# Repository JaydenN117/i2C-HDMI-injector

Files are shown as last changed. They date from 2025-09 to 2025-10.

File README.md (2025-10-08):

# i2C-HDMI-injector, Code and casing. Never ordered PCB concept too.


Injects i2c signal to Dasung Paperlike Pro monitor through HDMI on modern macs, work in progress, have not ordered. 
Reversed engineered signal by simply reading with Oscilloscope.
Did not order kicad and would redo differently to make assembly easier but it was more of a learning excersize.

[Dual HDMI Breakout](https://www.amazon.com/Teansic-Connector-Female-Connectors-Transfer/dp/B0CKN298QF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)
I ended up desoldering the pins to minimize footprint so perhaps a version [Without Presoldered headers](https://www.amazon.com/Cermant-Connector-Board%EF%BC%8C2-54-Connectors-Electronics/dp/B0DGT2GBF2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) would have been a better purchase

Refresh
Refresh

Clear
Clear
<br>
Screenshot 2025-09-27 at 11 06 51 AM


Hardware: 5V level Pro Micro Soldered to HDMI breakout... Any 5V level AVR bar would work.

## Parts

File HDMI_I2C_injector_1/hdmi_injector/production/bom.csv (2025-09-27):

Designator | Footprint | Quantity | Value | LCSC Part #
C1, C2 | 0603 | 2 | 100nF
D-SCL-1, D2, D6, D7, D8 | D_SOD-882 | 5 | SP3021-01ETG
D1, D3, D9 | D_SOD-882 | 3 | PESD5V0L1UL
J1 | HDMI-SMD_HDMI-GD-132PWB | 1 | HDMI_A_MAC
J2 | HDMI-SMD_HDMI-GD-132PWB | 1 | HDMI_A_DISPLAY_SIDE
J3 | CONN_BM03B-SRSS-TBLFSN_JST | 1 | BM03B-SRSS-TBLFSN
J4 | CONN4_BM04B-SRSS_JST | 1 | BM04B-SRSS-TB
R1, R2 | 0603 | 2 | 10kΩ
R4 | 0603 | 1 | 0Ω
U1 | SOIC-8_3.9x4.9mm_P1.27mm | 1 | ATtiny402-SS
U3 | SOT-363_SC-70-6 | 1 | LM66100DCK

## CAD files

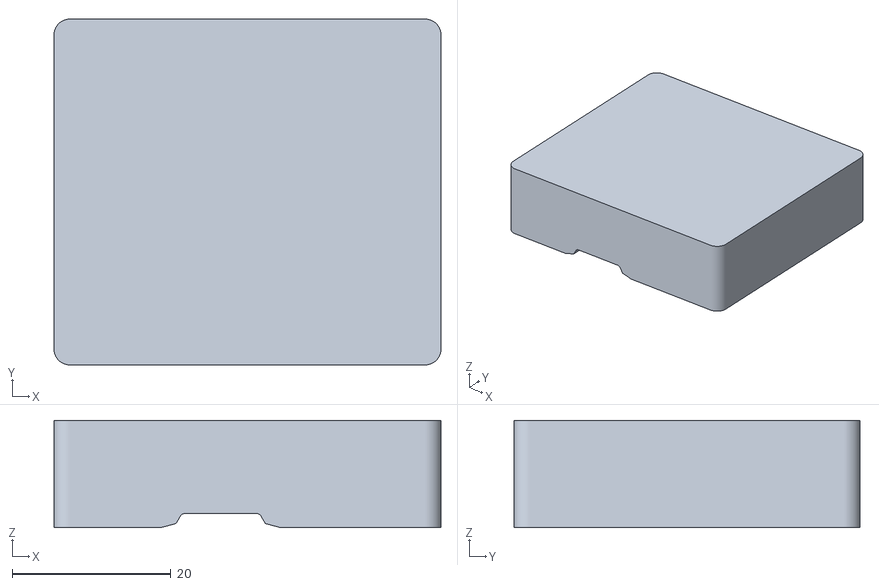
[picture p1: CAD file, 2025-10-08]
Top_casing.stl
48.7 x 43.5 x 13.5

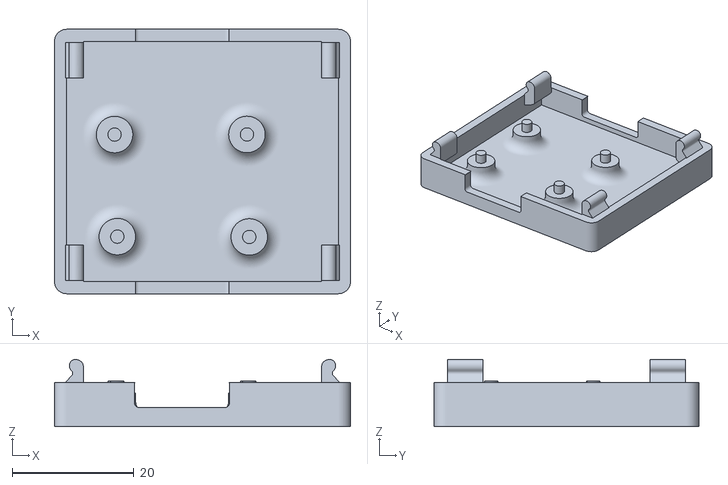
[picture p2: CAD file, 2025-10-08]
bottom_casing.stl
48.7 x 43.5 x 11.1

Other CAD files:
Hdmi board with casing v11.f3z

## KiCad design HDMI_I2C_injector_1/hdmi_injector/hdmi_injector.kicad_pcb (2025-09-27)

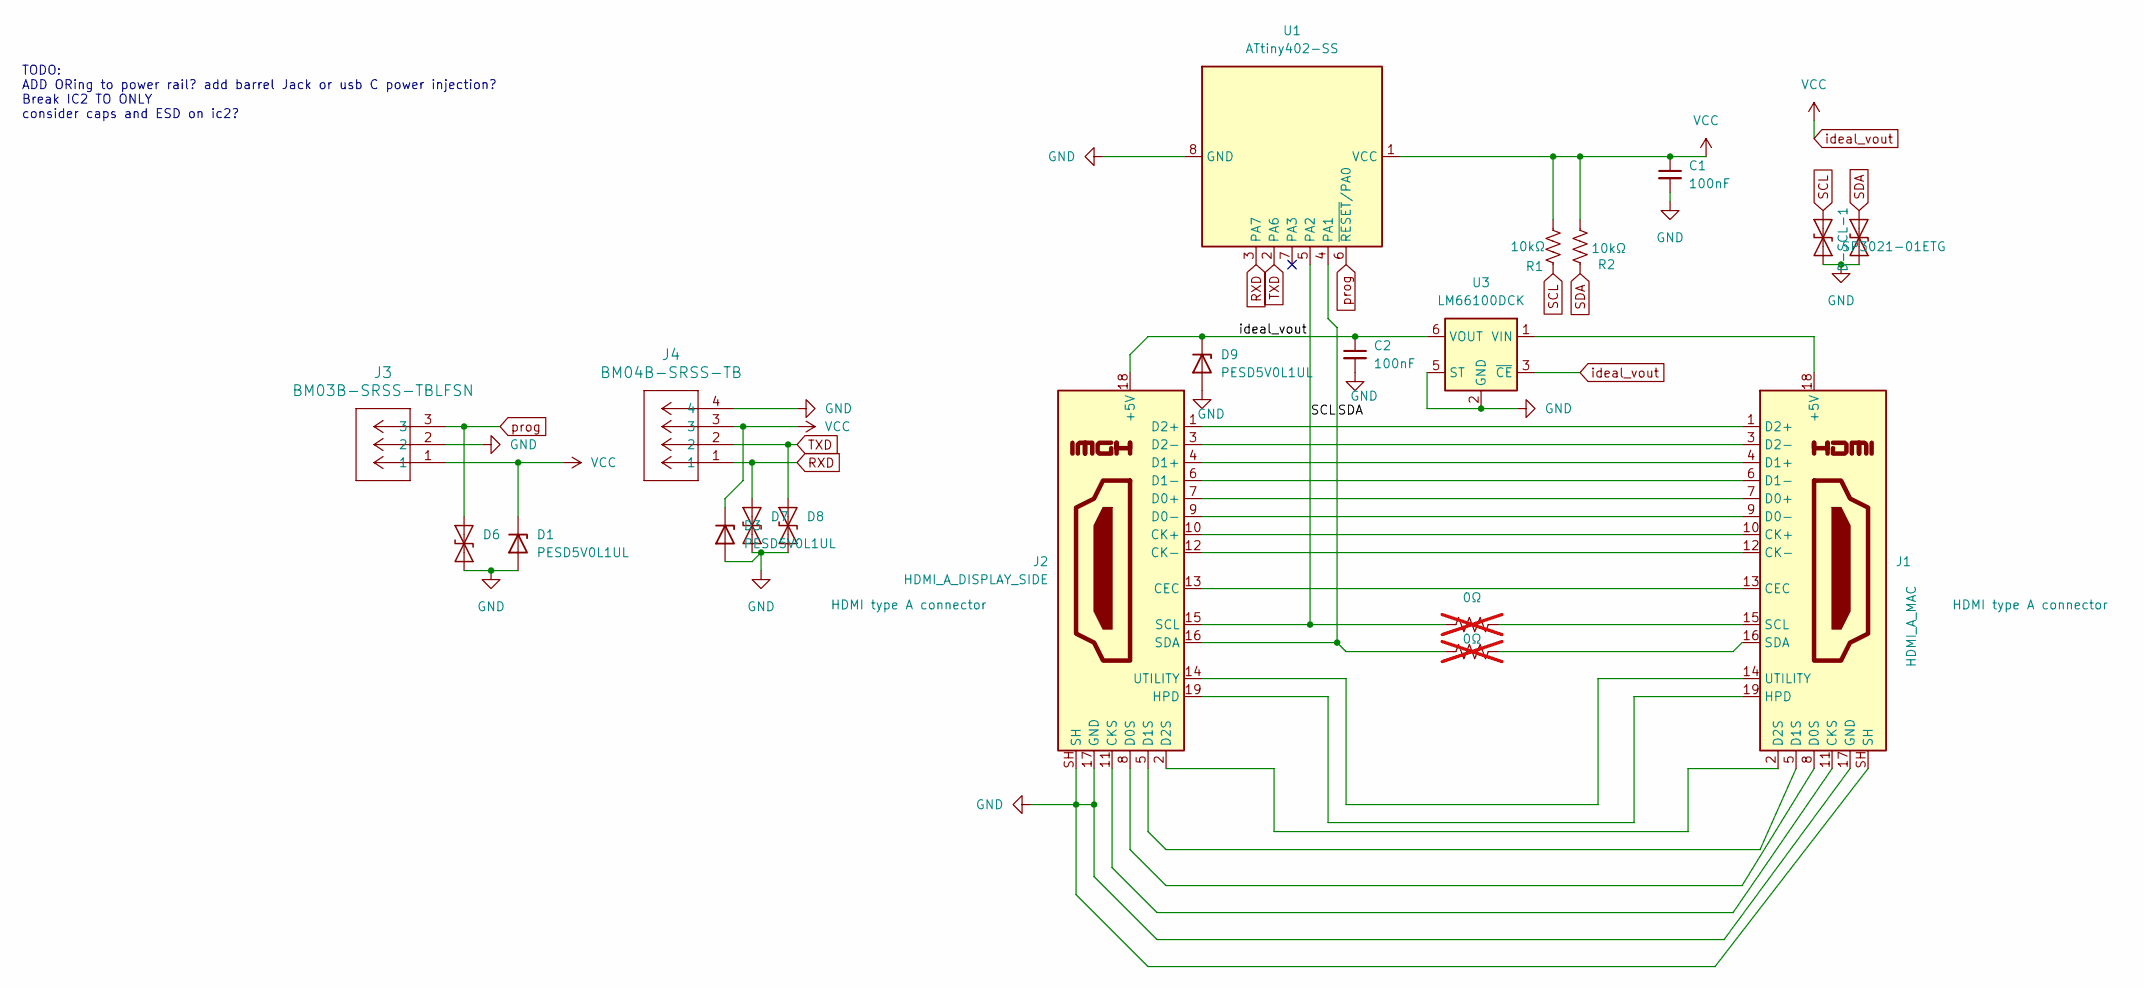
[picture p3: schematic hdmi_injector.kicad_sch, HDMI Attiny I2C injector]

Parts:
C1, C2: 100nF; C_0603_1608Metric_Pad1.08x0.95mm_HandSolder
D1, D3, D9: PESD5V0L1UL; D_SOD-882
D2, D6, D7, D8: SP3021-01ETG; D_SOD-882
D-SCL-1: SP3021-01ETG; D_SOD-882
J1: HDMI_A_MAC; HDMI-SMD_HDMI-GD-132PWB
J2: HDMI_A_DISPLAY_SIDE; HDMI-SMD_HDMI-GD-132PWB
J3: BM03B-SRSS-TBLFSN; CONN_BM03B-SRSS-TBLFSN_JST
J4: BM04B-SRSS-TB; CONN4_BM04B-SRSS_JST
R1, R2: 10kΩ; R_0603_1608Metric_Pad0.98x0.95mm_HandSolder
R3, R4: 0Ω; R_0603_1608Metric_Pad0.98x0.95mm_HandSolder; not fitted
U1: ATtiny402-SS; SOIC-8_3.9x4.9mm_P1.27mm
U3: LM66100DCK; SOT-363_SC-70-6

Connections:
GND: C1.2, C2.2, D1.2 (A), D2.1 (A1), D3.2 (A), D6.1 (A1), D7.1 (A1), D8.1 (A1), D9.2 (A), D-SCL-1.1 (A1), J1.17 (GND), J1.SH, J2.17 (GND), J2.SH, J3.2, J4.4, U1.8 (GND), U3.2 (GND), U3.5 (ST)
unnamed: J1.18 (+5V), U3.1 (VIN)
unnamed: J1.13 (CEC), J2.13 (CEC)
unnamed: J1.10 (CK+), J2.10 (CK+)
unnamed: J1.12 (CK-), J2.12 (CK-)
unnamed: J1.11 (CKS), J2.11 (CKS)
unnamed: J1.7 (D0+), J2.7 (D0+)
unnamed: J1.9 (D0-), J2.9 (D0-)
unnamed: J1.8 (D0S), J2.8 (D0S)
unnamed: J1.4 (D1+), J2.4 (D1+)
unnamed: J1.6 (D1-), J2.6 (D1-)
unnamed: J1.5 (D1S), J2.5 (D1S)
unnamed: J1.1 (D2+), J2.1 (D2+)
unnamed: J1.3 (D2-), J2.3 (D2-)
unnamed: J1.2 (D2S), J2.2 (D2S)
unnamed: J1.19 (HPD), J2.19 (HPD)
unnamed: J1.15 (SCL), R3.2
unnamed: J1.16 (SDA), R4.2
unnamed: J1.14 (UTILITY), J2.14 (UTILITY)
RXD: D7.2 (A2), J4.1, U1.3 (PA7)
SCL: D-SCL-1.2 (A2), J2.15 (SCL), R1.1, R3.1, U1.5 (PA2)
SDA: D2.2 (A2), J2.16 (SDA), R2.1, R4.1, U1.4 (PA1)
TXD: D8.2 (A2), J4.2, U1.2 (PA6)
ideal_vout: C1.1, C2.1, D1.1 (K), D3.1 (K), D9.1 (K), J2.18 (+5V), J3.1, J4.3, R1.2, R2.2, U1.1 (VCC), U3.3 (~CE), U3.6 (VOUT)
prog: D6.2 (A2), J3.3, U1.6 (~RESET/PA0)

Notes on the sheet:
TODO: ADD ORing to power rail? add barrel Jack or usb C power injection? Break IC2 TO ONLY consider caps and ESD on ic2?

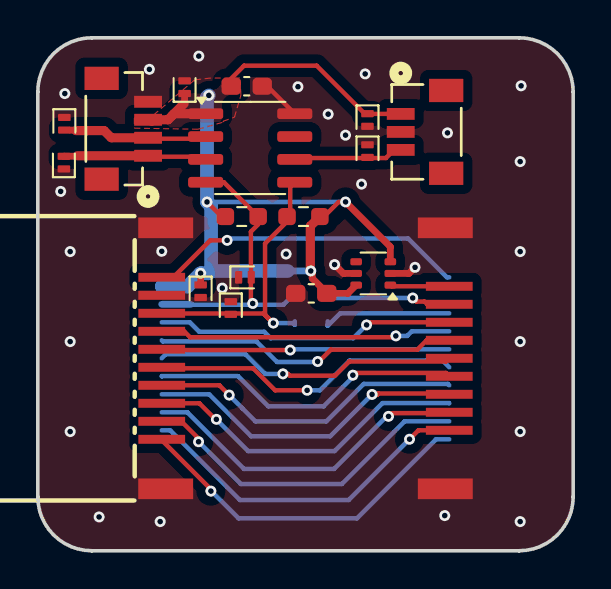
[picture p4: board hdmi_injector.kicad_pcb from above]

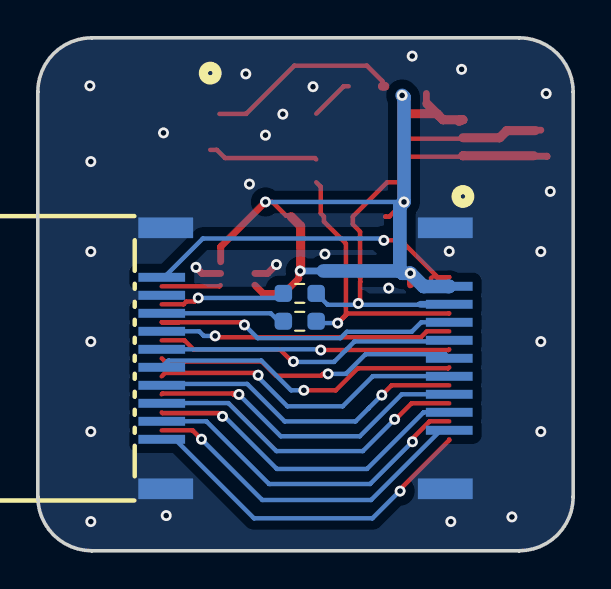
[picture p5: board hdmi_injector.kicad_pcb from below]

Board: 4 copper layers, 29.7 x 28.5 mm, 20 parts (3 on the bottom side), 25 nets.

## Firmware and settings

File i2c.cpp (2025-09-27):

#include <Arduino.h>
#include <Wire.h>

// Dasung display I2C address
const uint8_t DASUNG_I2C_ADDR = 0x37;

// Command sequences
const uint8_t CMD_SEQUENCE_1[] = {0x51, 0x84, 0x03, 0x08, 0x01, 0x01, 0xB0};
const uint8_t CMD_CLEAR[] = {0x51, 0x84, 0x03, 0x08, 0x06, 0x02, 0xB4};

void sendCommand(const uint8_t* cmd, uint8_t length) {
  Wire.beginTransmission(DASUNG_I2C_ADDR);
  for (uint8_t i = 0; i < length; i++) {
    Wire.write(cmd[i]);
  }
  Wire.endTransmission();
}

void setup() {
  // Initialize serial for debugging
  Serial.begin(115200);

  
  Serial.println("Dasung Display Hack Starting...");
  
  // Initialize I2C
  Wire.begin();
  
  // Small delay to ensure I2C is ready
  delay(100);
  
  // Send clear command on startup
  Serial.println("Sending clear command...");
  sendCommand(CMD_CLEAR, sizeof(CMD_CLEAR));
  
  delay(100);
  
  // Send the first command sequence
  Serial.println("Sending command sequence 1...");
  sendCommand(CMD_SEQUENCE_1, sizeof(CMD_SEQUENCE_1));
  
  Serial.println("Setup complete!");
}

void loop() {
  sendCommand(CMD_SEQUENCE_1, sizeof(CMD_SEQUENCE_1));
  // Small delay to prevent overwhelming the serial buffer
  delay(300);
}

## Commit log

2025-09-27 Added KiCAD files for v1
    [bom.csv, designators.csv, hdmi_injector.kicad_pcb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]
2025-10-08 CAD Files
    3D printed Casing and dummy pcb of the breakout board.
    [Hdmi board with casing v11.f3z, Top_casing.stl, bottom_casing.stl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]
